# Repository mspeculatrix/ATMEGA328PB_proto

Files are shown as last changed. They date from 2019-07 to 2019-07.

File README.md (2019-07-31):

# ATMEGA328PB breakout & prototyping board

This is a breakout/prototyping board for the ATMEGA328PB microcontroller which comes in the TQFP-32 format. It allows programming of the chip and breaks out all the pins to standard DuPont headers for project prototyping. My plan is to mount this PCB on a baseboard alongside a breadboard.

The microcontroller chip is placed in a TQFP-32 adapter, such as [this one](https://www.ebay.com/itm/1Pcs-TQFP32-QFP32-TO-DIP32-28-IC-Programmer-Adapter-Chip-Test-Socket-Pitch-Black/173689092477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). These come with carrier boards to make the adapter fit standard DIP footprints. But my board doesn't use this - it just uses the main adapter itself which I have soldered into my PCB.

The pins for the four ports, B, C, D and E are gathered together logically (whereas they are somewhat scattered around on the microcontroller chip pinout itself).

### Features
* The AVCC pin is connected to VCC using a low-pass filter - ie, via a 10µH inductor with a 0.1µF capacitor to GND. This is Atmel's recommended setup which you want to use the analogue features of the microcontroller but don't want to go to the trouble of providing a separate analogue supply.
* There's a standard 6-pin header to connect an ISP programmer auch as the ATMEL-ICE.
* The ~RESET pin (PC6) has a pullup resistor and a tactile button to reset the microcontroller.
* The standard I2C pins (PC4, PC5) both have two additional pins for easy use of more than one I2C device. The additional pins are accompanied by +5V and GND pins. Onboard 10kΩ pullup resistors can be selected or deselected using jumpers.
* Female headers allow the use of an external crystal. This can be selected or deselected using jumpers. Onboard 22pF capacitors are connected between each leg of the crystal and GND.
* The standard UART pins – RX (PD0) and TX (PD1) have additional pins. These are in a row of six pins, including a GND connection, designed to match the normal order of connections on an FTDI USB-serial cable. Two of the other pins - RTS and CTS - are connected to two more pins. You can then use short female-female jumper cables to connect RTS and DTS to the GPIO pins of your choice.
* Finally, there are three lots of 4-pin connectors all tied to GND. Marked as 'test points', these are for the easy attachment of the GND clip for oscilloscope probes.
* There's an on-off slide switch for power. It is possible, however, that the board will be back-powered through any signals applied to the GPIO pins. Other than buffering every pin, I don't see any way to avoid this, so it's just something to watch out for.

### Notes
* The power connector is a simple two-pin header. NO REVERSE POLARITY PROTECTION IS PROVIDED. Nor is there any over-voltage protection.
* The board is intended to be powered by 5V, although it might work on 3.3V (I haven't thought that through).

### Progress
I've received the first batch of Rev 1.0 boards and have made up one, hand-soldered board. And, so far, it has worked flawlessly.

***
### Resources
* [Background to the project](https://mansfield-devine.com/speculatrix/2019/07/atmega328pb-breakout-and-prototyping-board/)

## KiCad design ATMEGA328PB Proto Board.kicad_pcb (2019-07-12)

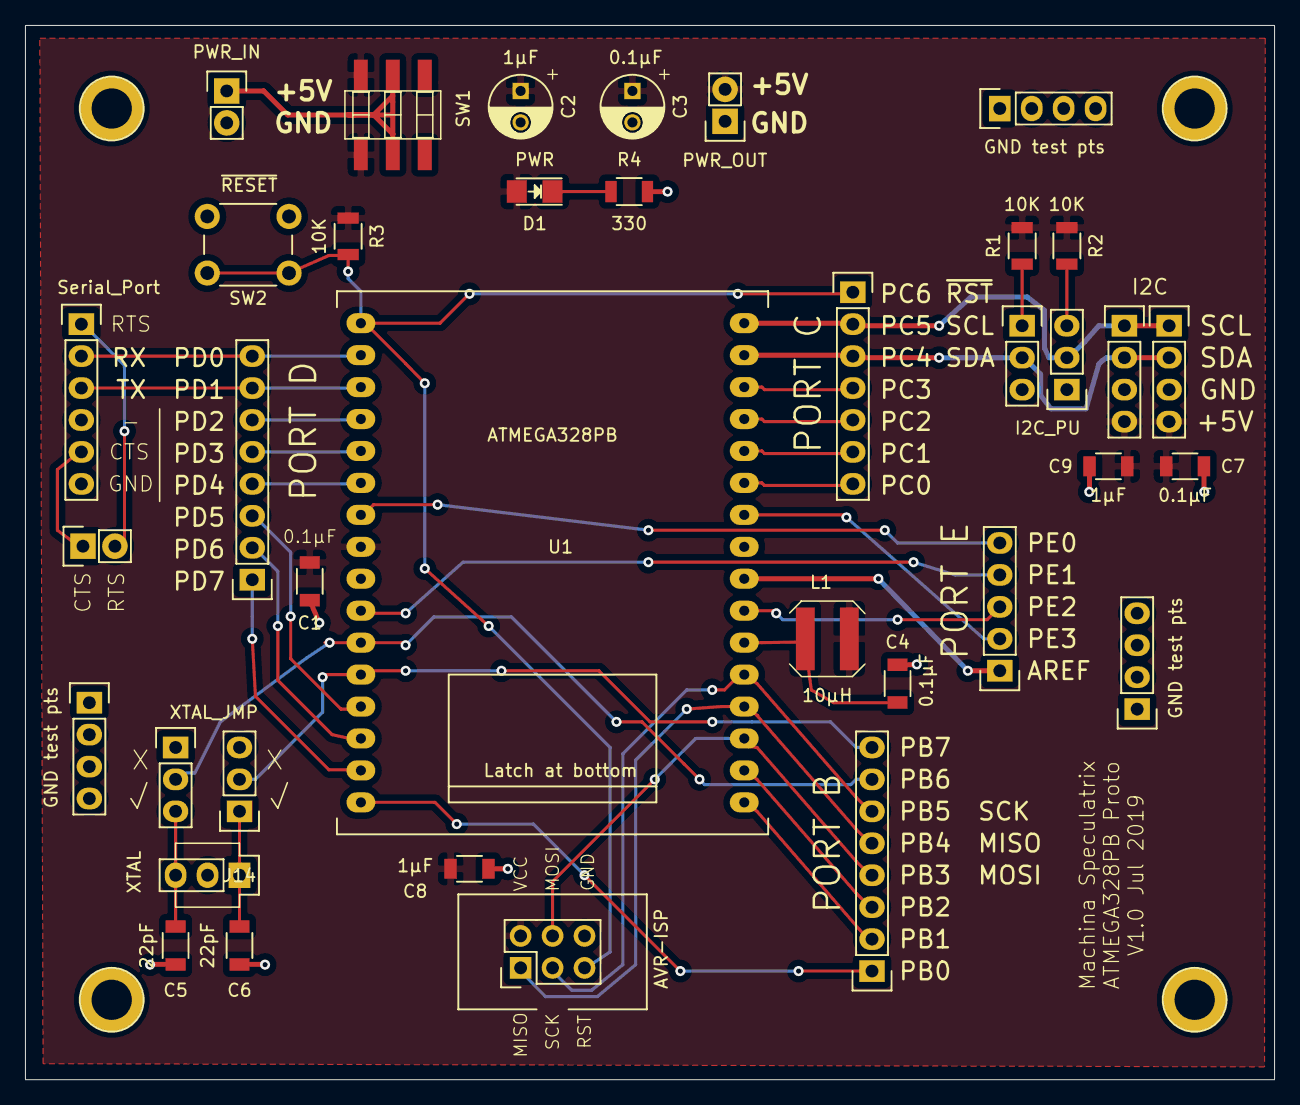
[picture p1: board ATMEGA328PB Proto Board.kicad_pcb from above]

Board: 2 copper layers, 99.3 x 83.8 mm, 37 parts (0 on the bottom side), 39 nets.

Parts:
C1, C4, C7: 0.1µF; C_1206
C2: 1µF; C_Radial_D5_L6_P2.5
C3: 0.1µF; C_Radial_D5_L6_P2.5
C5, C6: 22pF; C_1206
C8, C9: 1µF; C_1206
CONN1: AVR-ISP; AVR_ISP_HE10_2x3
D1: PWR; LED_1206
J1: PWR_IN; Pin_Header_Straight_1x02
J2: PORT B; Pin_Header_Straight_1x08
J3: PORT C; Pin_Header_Straight_1x07
J4: PORT D; Pin_Header_Straight_1x08
J5: PORT E; Pin_Header_Straight_1x05
J6, J7: I2C; Pin_Header_Straight_1x04
J9: I2C_PU; Pin_Header_Straight_1x03
J10: SCL_PU; Pin_Header_Straight_1x03
J11: PWR_OUT; Pin_Header_Straight_1x02
J12: XTAL_JMP; Pin_Header_Straight_1x03
J13: XTAL; Pin_Header_Straight_1x03
J14: XTAL2_JMP; Pin_Header_Straight_1x03
J15, J16, J19: GND test pts; Pin_Header_Straight_1x04
J17: Serial_Port; Pin_Header_Straight_1x06
J18: RTS-CTS; Pin_Header_Straight_1x02
L1: 10µH; Inductor_Bourns-SRN5020
R1, R2, R3: 10K; R_1206
R4: 330; R_1206
SW1: SW_DPDT; SW_SMD_DPDT
SW2: ~RESET; SW_PUSH_6mm
U1: ATMEGA328PB; DIP-32_TQFP_ZIF

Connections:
/AVCC: C4.1, L1.2, U1.18
/CTS: J17.5, J18.1
/PB0: J2.1, U1.12
/PB1: J2.2, U1.13
/PB2: J2.3, U1.14
/PB6: J2.7, J12.2, U1.7
/PB7: J2.8, J14.2, U1.8
/PC0: J3.7, U1.23
/PC1: J3.6, U1.24
/PC2: J3.5, U1.25
/PC3: J3.4, U1.26
/PD2: J4.6, U1.32
/PD3: J4.5, U1.1
/PD4: J4.4, U1.2
/PD5: J4.3, U1.9
/PD6: J4.2, U1.10
/PD7: J4.1, U1.11
/PE0: J5.5, U1.3
/PE1: J5.4, U1.6
/PE2: J5.3, U1.19
/PE3: J5.2, U1.22
/RTS: J17.1, J18.2
AREF: J5.1, U1.20
GND: C1.2, C2.2, C3.2, C4.2, C5.2, C6.2, C7.2, C8.2, C9.2, CONN1.6, J1.2, J6.3, J7.3, J11.1, J15.1, J15.2, J15.3, J15.4, J16.1, J16.2, J16.3, J16.4, J17.6, J19.1, J19.2, J19.3, J19.4, R4.2, SW2.2, U1.5, U1.21
unnamed: C5.1, J12.3, J13.3
unnamed: C6.1, J13.1, J14.1
unnamed: D1.1, R4.1
unnamed: J1.1, SW1.2, SW1.5
unnamed: J9.1, R1.2
unnamed: J10.3, R2.2
PB3_MOSI: CONN1.4, J2.4, U1.15
PB4_MISO: CONN1.1, J2.5, U1.16
PB5_SCK: CONN1.3, J2.6, U1.17
PC4_SDA: J3.3, J6.2, J7.2, J9.2, U1.27
PC5_SCL: J3.2, J6.1, J7.1, J10.2, U1.28
PC6_~RST: CONN1.5, J3.1, R3.2, SW2.1, U1.29
PD0_RX: J4.8, J17.2, U1.30
PD1_TX: J4.7, J17.3, U1.31
VCC: C1.1, C2.1, C3.1, C7.1, C8.1, C9.1, CONN1.2, D1.2, J6.4, J7.4, J11.2, L1.1, R1.1, R2.1, R3.1, SW1.1, SW1.4, U1.4
